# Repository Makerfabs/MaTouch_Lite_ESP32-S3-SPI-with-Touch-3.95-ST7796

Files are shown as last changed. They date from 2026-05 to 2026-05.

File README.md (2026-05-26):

# MaTouch_Lite_ESP32-S3-SPI-with-Touch-3.95-ST7796

## Introduction

The MaTouch Lite 3.95 adopts an SPI screen driven by ST7796 chip with a resolution of 480×320, matched with NS2009 resistive touch screen. It is equipped with ESP32-S3 main controller, built-in 16M Flash and 8M PSRAM. Adopting SPI display design, plenty of reserved GPIOs are available for secondary development via GPIO expansion interface. It also comes with SD card interface and USB native/USB2UART port.

Product Link: [MaTouch_Lite_ESP32-S3-SPI-with-Touch-3.95-ST7796](https://www.makerfabs.com/matouch-lite-esp32-s3-spi-resistive-touch-3-95-st7796.html)

Wiki Link:  [MaTouch_Lite_ESP32-S3-SPI-with-Touch-3.95-ST7796](https://wiki.makerfabs.com/MaTouch%20Lite%20ESP32_S3%20SPI%20with%20Touch%203.95%20ST7796.html)

Example：[LVGL_Touch](https://github.com/Makerfabs/MaTouch_Lite_ESP32-S3-SPI-with-Touch-3.95-ST7796#lvgl_touch)

## Feature

- Controller: ESP32-S3 controller 16M flash, 8M PSRAM
- Display: 3.95", 480x320 resolution , driver ST7796, SPI interface
- Touch Panel: Resistive, NS2009
- USB: 1 * USB_native, 1 * USB-to-UART
- USB-UART Driver: CH340K
- Power Supply: USB Type-C 5.0V(4.0V~5.25V); 3.7V Lipo battery
- Expansion interface: 2*JST1.25mm-4P GPIO, with cable included
- MicroSD Card Slot
- LCD Backlight control: Yes
- Arduino support: Yes
- LVGL support: Yes
- Operation temperature: -40℃ to +85℃

## Usage in Arduino IDE

- Install the Arduino IDE V1.8.19/V2.3.6
If you haven’t installed the ESP32 Board SDK yet, follow the steps in this [guide](https://wiki.makerfabs.com/Installing_ESP32_Add_on_in_Arduino_IDE.html) to get started quickly.

For the ESP32-S3 Development board version, we recommend using versions that have been verified, such as 2.0.16， which is more stable, and less prone to errors.

Note: Different computers may have different port numbers when connecting to a development board. Please select the correct port number based on the development board you are connecting to.

Please download the relevant driver libraries before using these demos.

1.Install Adafruit_BusIO v1.17.4

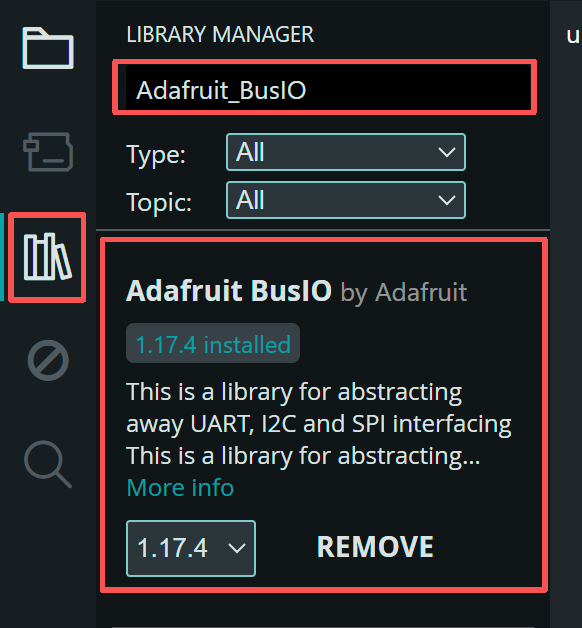
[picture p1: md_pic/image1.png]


2.Install Adafruit_SGP30_Sensor v2.0.3

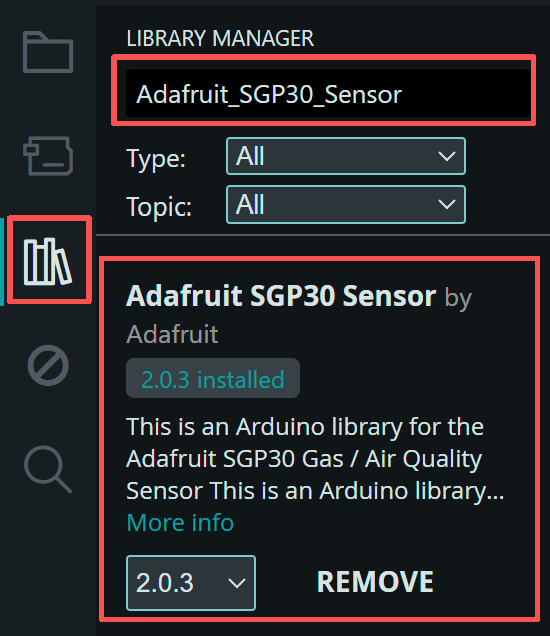
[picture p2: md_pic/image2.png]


3.Install Adafruit_SHT31_Library v2.2.2

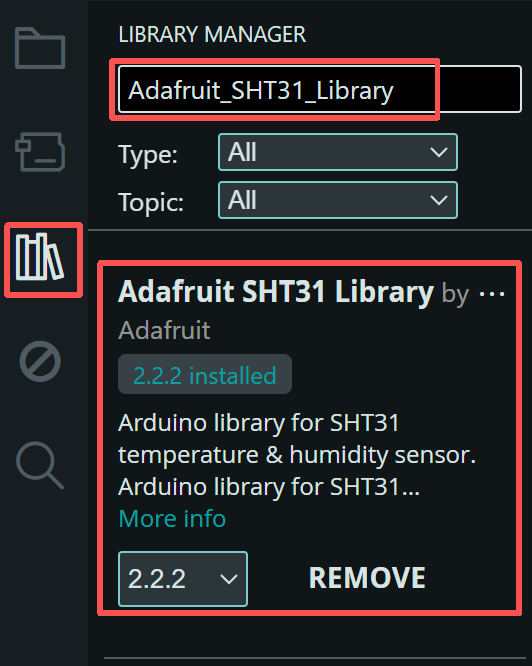
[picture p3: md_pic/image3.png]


## Example

### LVGL_Touch

This demonstration showcases the integrated application of display and touch. The screen initially shows an image with data such as temperature, humidity, CO2, TVOC,and touch point coordinates. If the screen is not touched within 10 seconds, it will automatically turn off. After the screen turns off, clicking on it will make it bright again and display the data.

- First, connect the Mabee module to the ESP32-S3 module correctly, as shown in the figure.

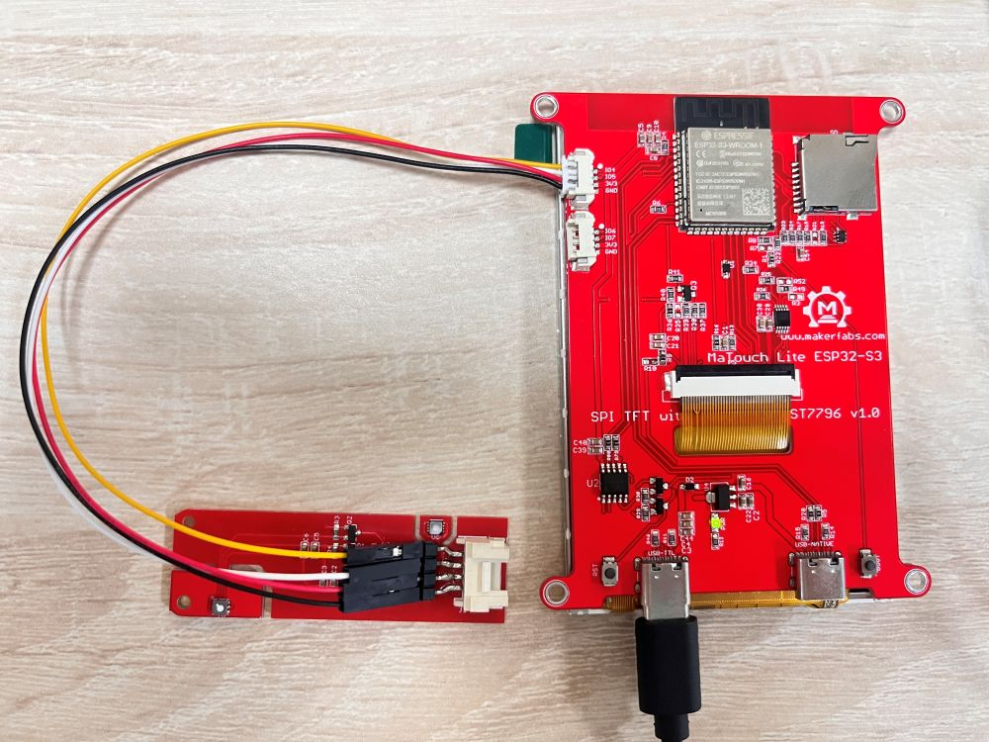
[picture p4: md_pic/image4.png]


- Download the library from [github](https://github.com/Makerfabs/MaTouch_Lite_ESP32-S3-SPI-with-Touch-3.95-ST7796/tree/main/example/LVGL_Touch/libraries)

Once the download is complete, copy these libraries into the Arduino library.

- The default is usually in the "C:\Users\Your username\Documents\Arduino\libraries"

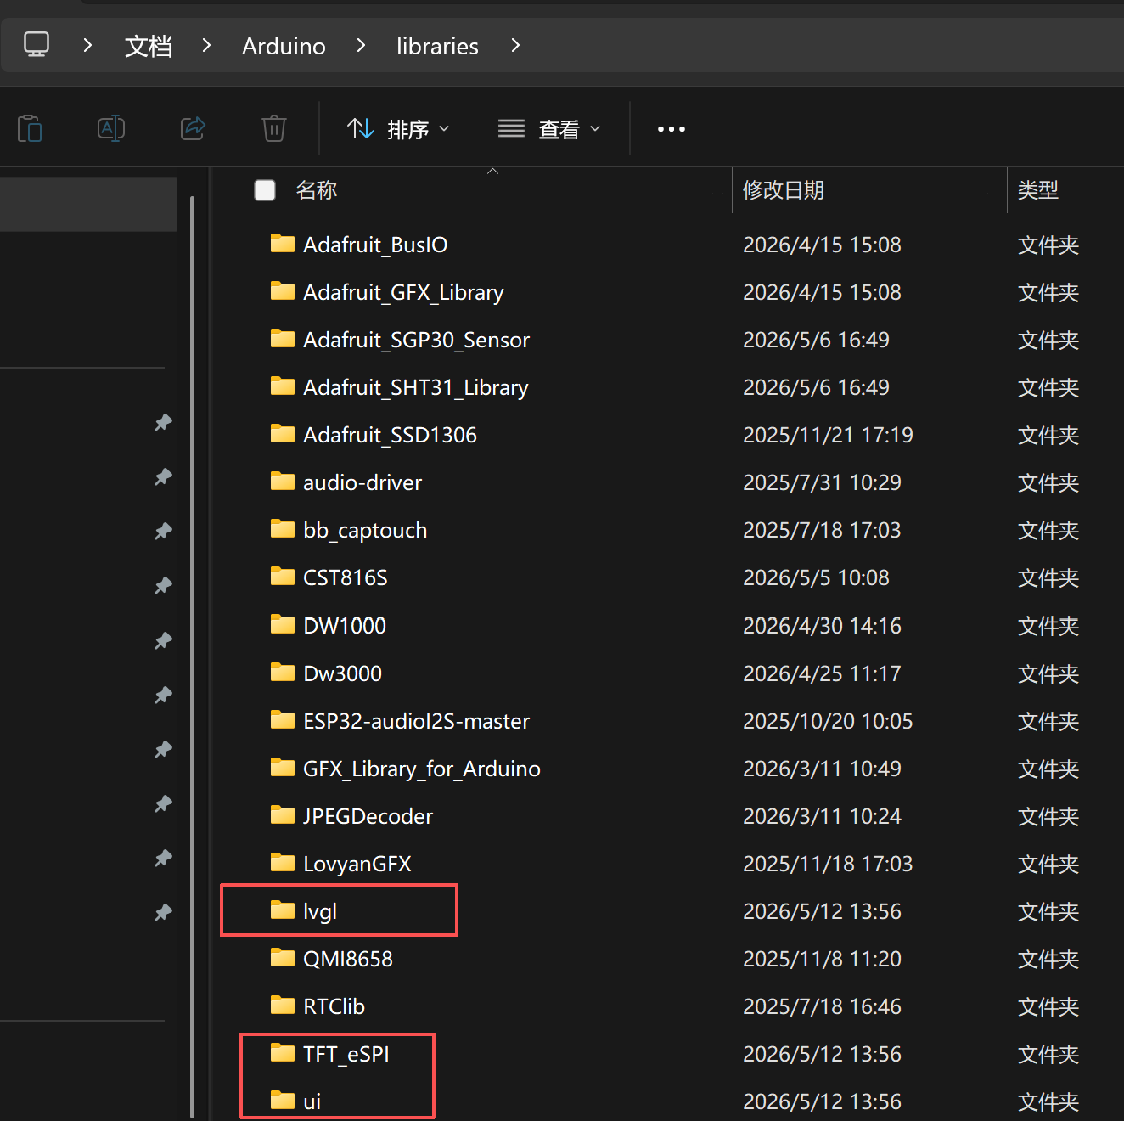
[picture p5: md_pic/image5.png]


**Note: If the UI, LVGL or TFT_eSPI library already exists in your Arduino libraries folder, please delete them first, then install the new version of the UI, LVGL or TFT_eSPI library.**

- Open the [LVGL_Touch](https://github.com/Makerfabs/MaTouch_Lite_ESP32-S3-SPI-with-Touch-3.95-ST7796/blob/main/example/LVGL_Touch/ui/ui.ino) by Arduino.

Connect the board to the computer using a Type-C USB data cable and via USB-TTL, and select the development board "ESP32S3 Dev Module" and the port.

- Select "Tools > board:"xxx" > ESP32 > ESP32S3 Dev Module".
- Select "Tools > Port",Select the port number of the board.
- Select Flash Size is 16MB(128MB), Partition Scheme is 16M Flash (3MB APP/9.9MB FATFS), PSRAM is OPI PSRAM.

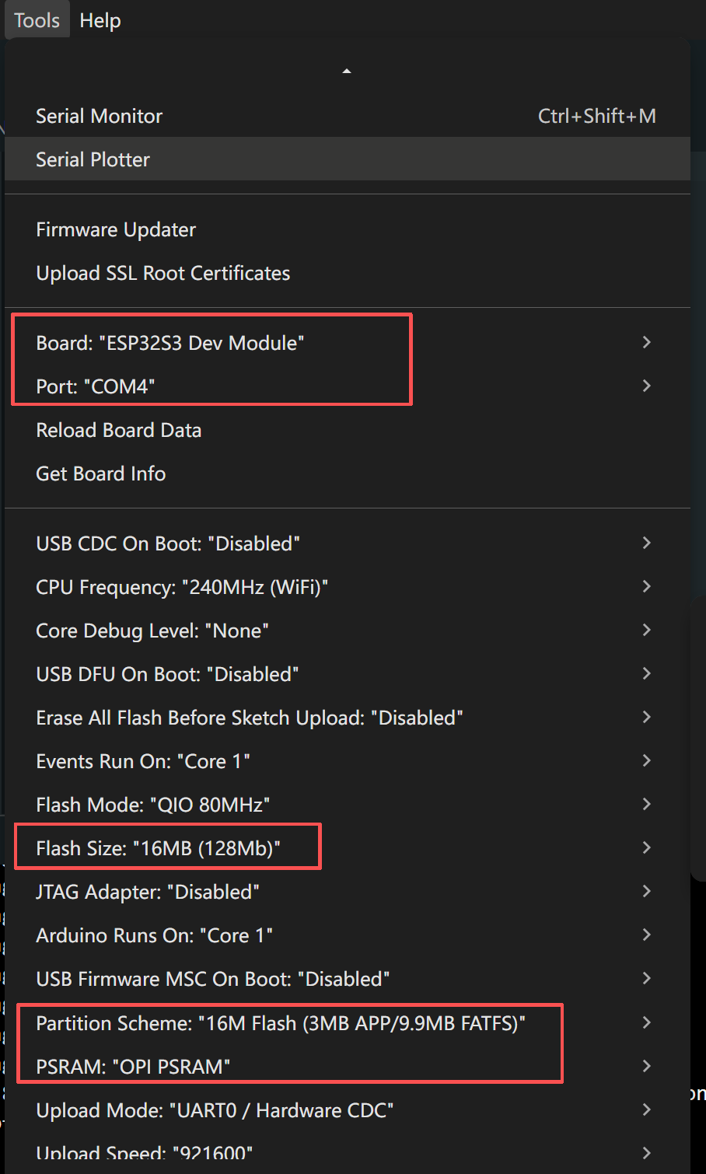
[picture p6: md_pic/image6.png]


- Click the Upload button in the Arduino IDE and wait a few times while the code compiles and uploads to your board.

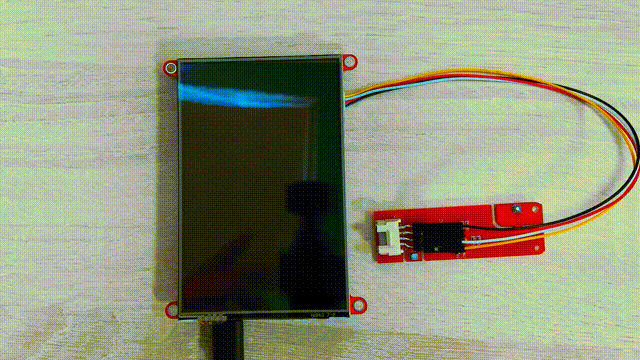
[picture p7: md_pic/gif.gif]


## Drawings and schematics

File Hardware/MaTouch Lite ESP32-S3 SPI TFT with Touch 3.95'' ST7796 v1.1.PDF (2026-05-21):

POWER | USB to TTL

# SD Card

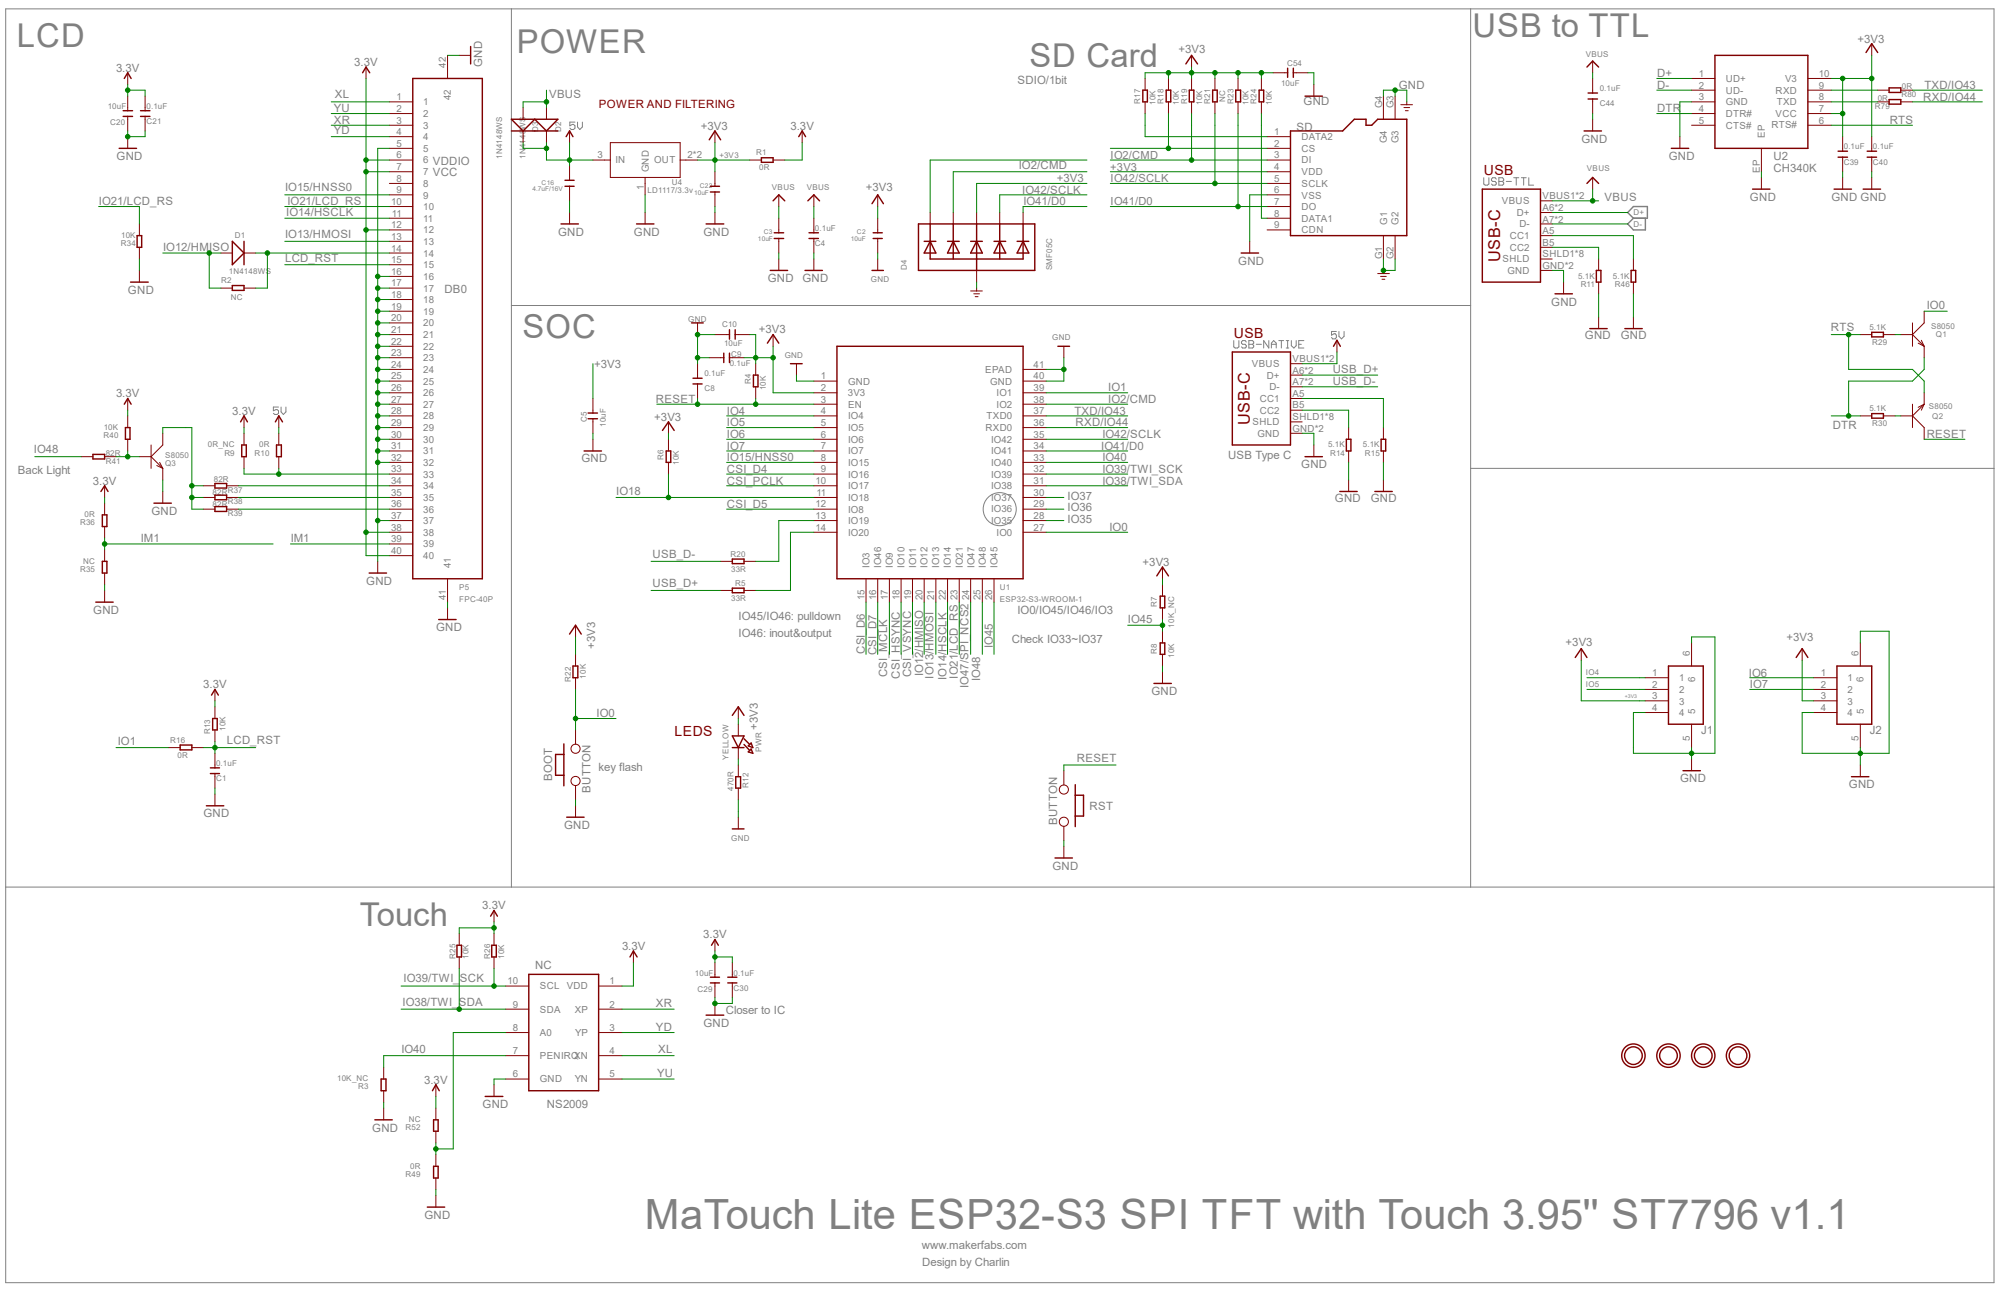
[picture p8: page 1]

MaTouch Lite ESP32-S3 SPI TFT with Touch 3.95'' ST7796 v1.1

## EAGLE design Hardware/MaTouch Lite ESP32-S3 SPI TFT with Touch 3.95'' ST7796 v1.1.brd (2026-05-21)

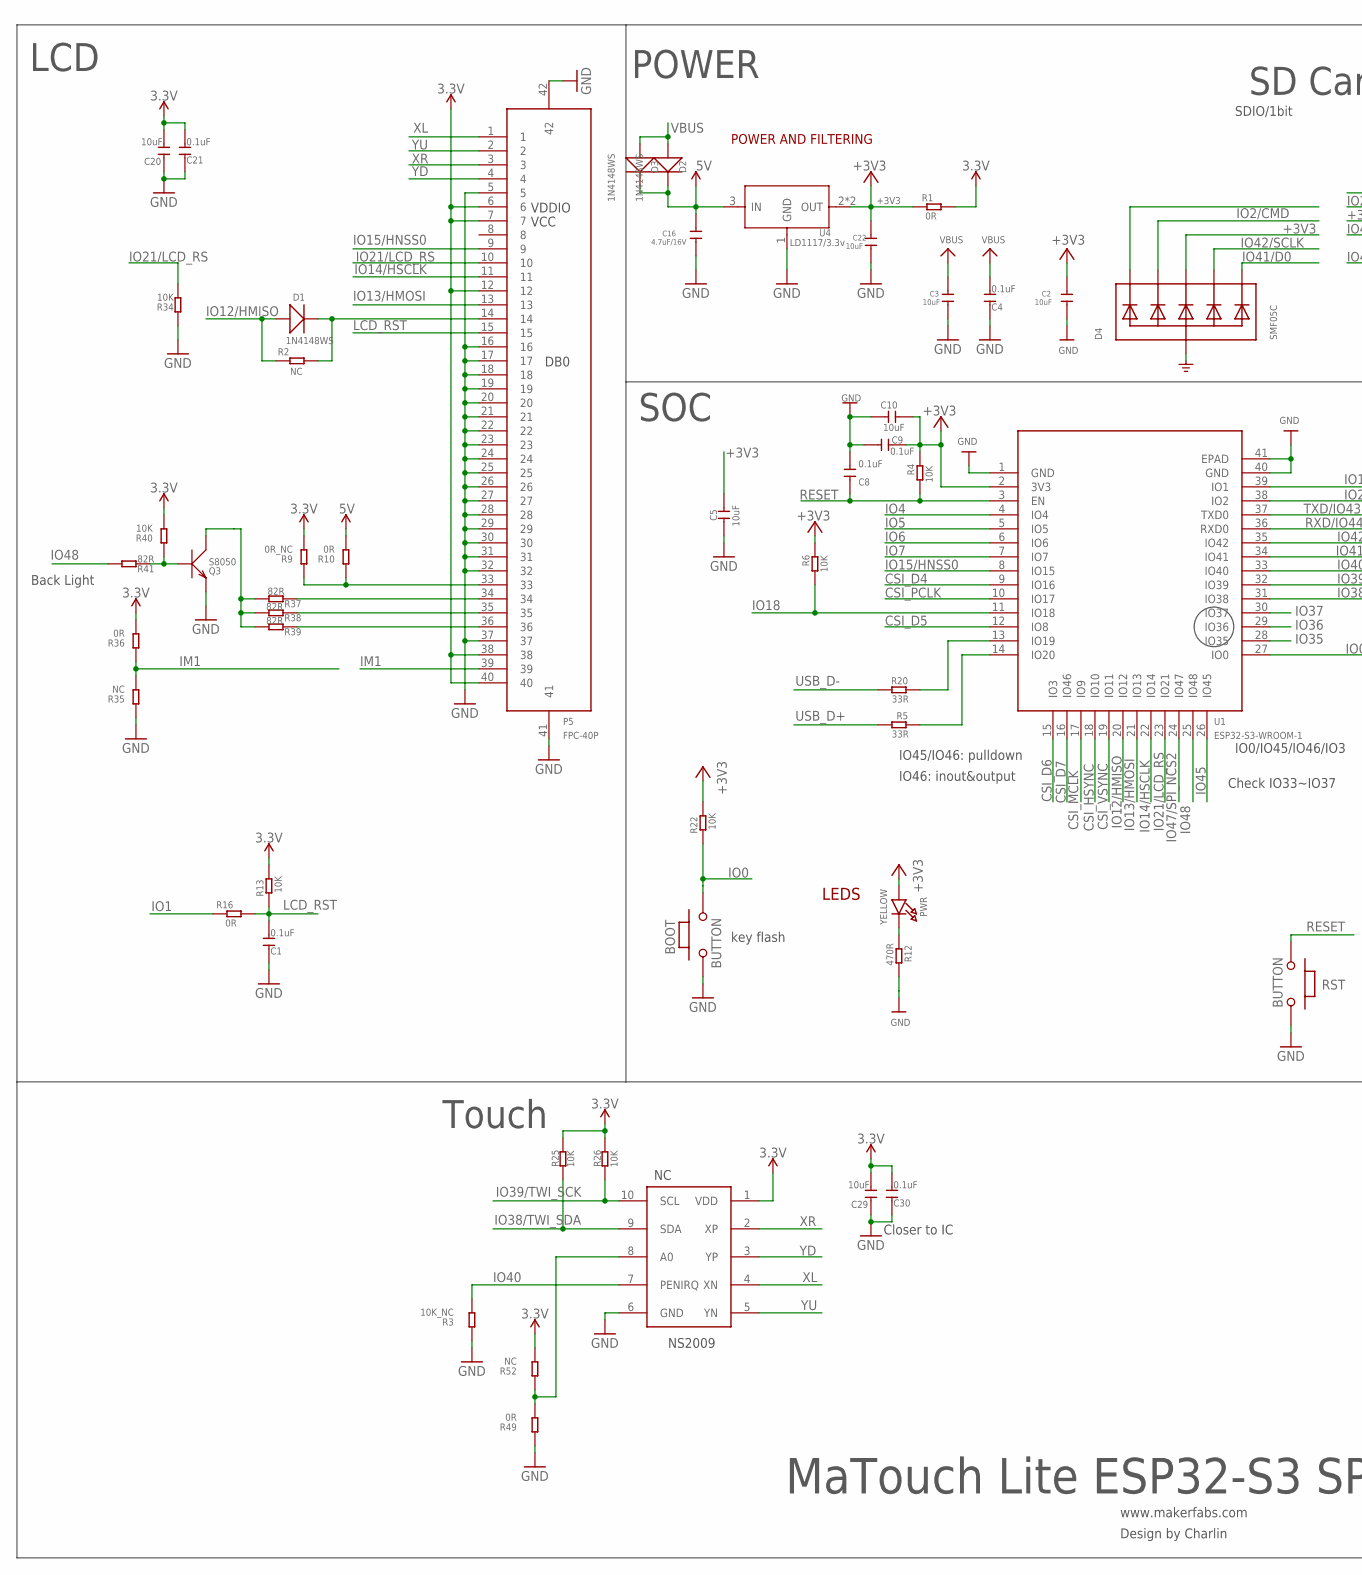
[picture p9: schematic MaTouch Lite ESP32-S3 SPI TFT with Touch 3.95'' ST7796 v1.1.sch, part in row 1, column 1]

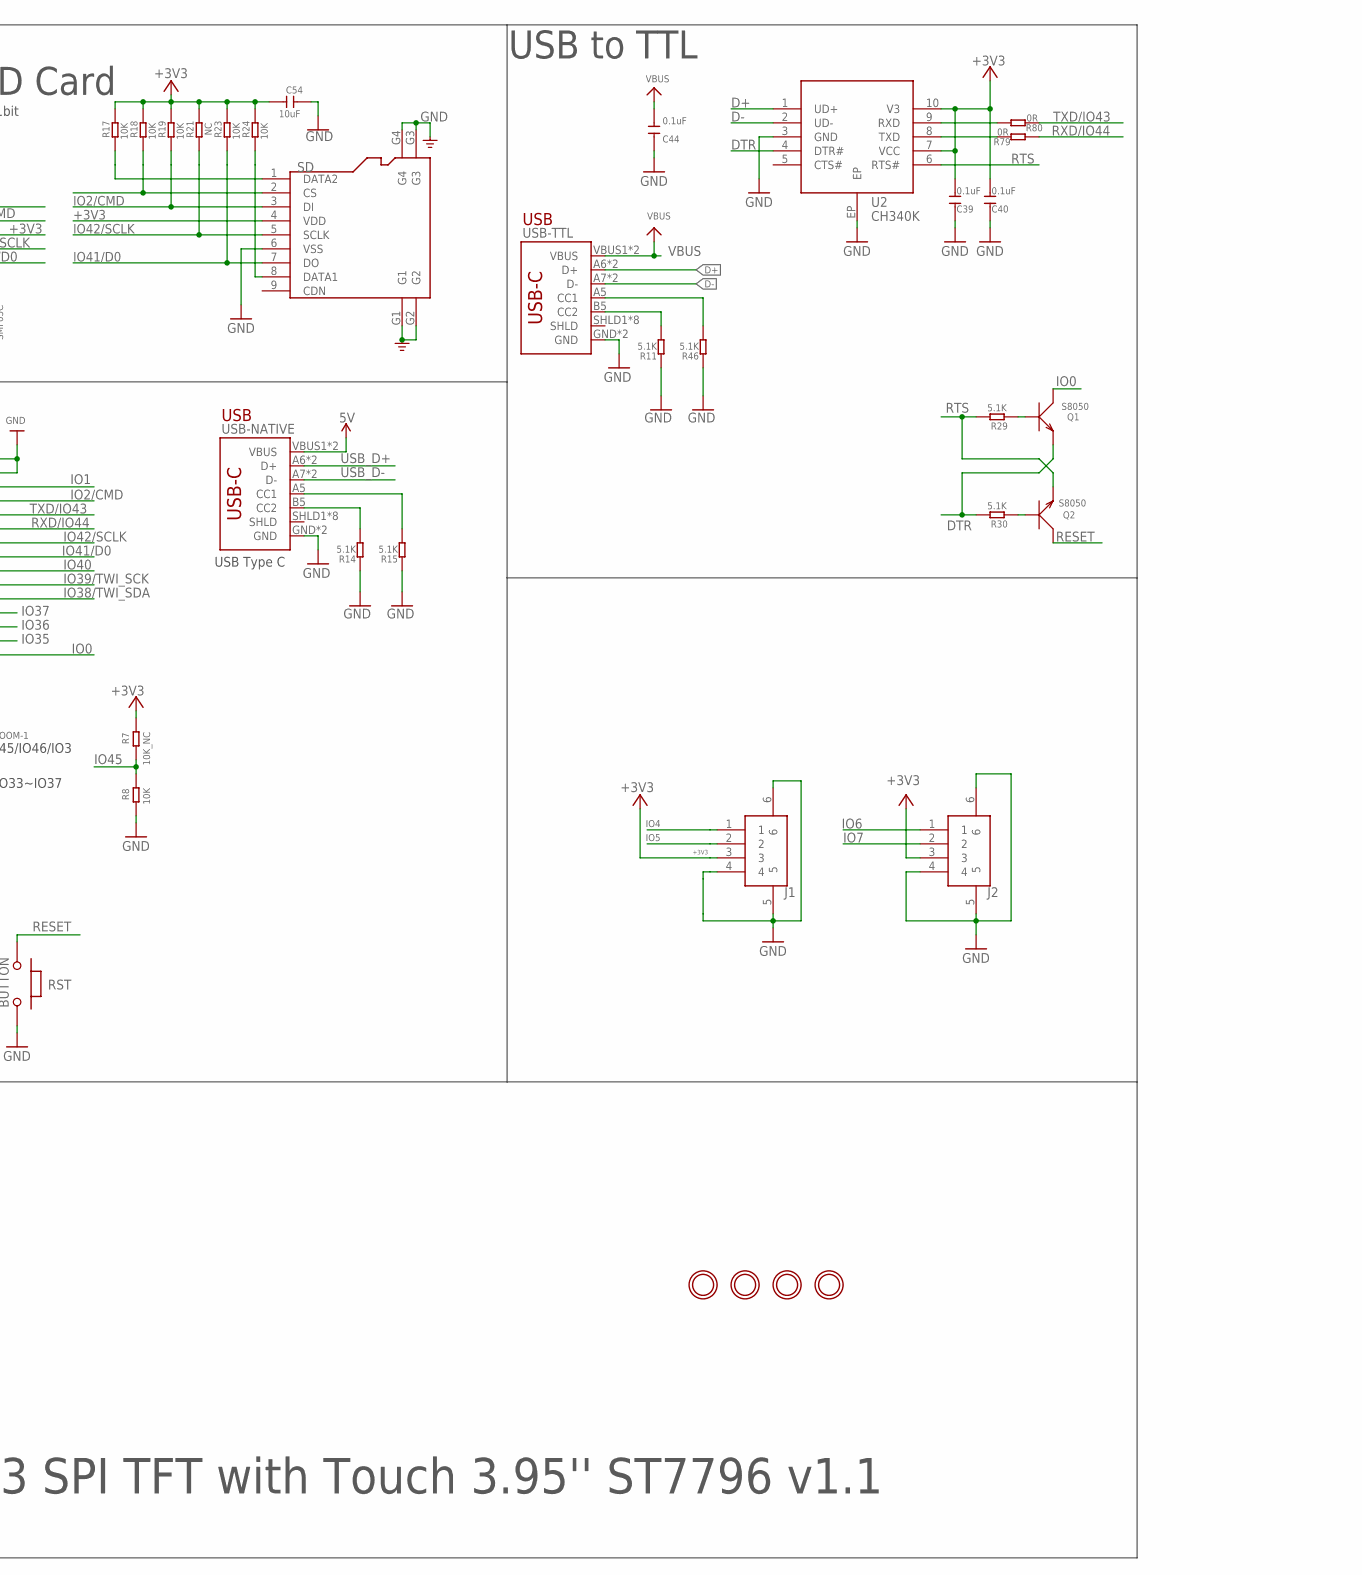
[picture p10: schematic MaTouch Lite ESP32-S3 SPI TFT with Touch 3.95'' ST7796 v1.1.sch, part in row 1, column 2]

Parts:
BOOT: BUTTON; 157SW
C1, C4, C8, C9, C21, C30, C39, C40, C44: 0.1uF; DISCRETE_C0603
C2, C3, C22: 10uF; 0603
C5, C10, C20, C29, C54: 10uF; DISCRETE_C0603
C16: 4.7uF/16V; 0603
D1, D2, D3: 1N4148WS; SOD323
D4: SMF05C; SOT363
H1, H2, H3, H4: MICROBUILDER_MOUNTINGHOLE3.0THIN; MICROBUILDER_MOUNTINGHOLE_3.0_PLATEDTHIN
J1, J2: CON4-1.25P-SMD; SMD4-125P-1000L525W350H
P5: FPC-40P; SMD42-50P-2560L490W
PWR: YELLOW; CHIPLED_0805_NOOUTLINE
Q1, Q2, Q3: S8050; SOT23
R1, R16, R79, R80: 0R; R0603
R2, R21: NC; R0603
R3: 10K_NC; DISCRETE_R0603
R4, R6, R8, R13, R17, R18, R19, R22, R23, R24, R25, R26: 10K; R0603
R5, R20: 33R; R0603
R7: 10K_NC; R0603
R9: 0R_NC; DISCRETE_R0603
R10, R36, R49: 0R; DISCRETE_R0603
R11, R14, R15, R46: 5.1K; DISCRETE_R0603
R12: 470R; R0603
R29, R30: 5.1K; R0603
R34, R40: 10K; DISCRETE_R0603
R35, R52: NC; DISCRETE_R0603
R37, R38, R39, R41: 82R; DISCRETE_R0603
RST: BUTTON; 157SW
SD: HOLDER-MICROSD-9P; 9P-SMD-W/-RING
U1: ESP32-S3-WROOM-1
U2: CH340K; ESOP-10-EP-150MIL
U4: LD1117/3.3v; SOT89
U8: NS2009; MSOP10
USB-NATIVE: USB_C5; USB-C-16P-5
USB-TTL: USB_C5; USB-C-16P-5

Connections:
5V: C16.1, D2.-, D3.-, R10.2, U4.3 (IN), USB-NATIVE.VBUS1 (VBUS), USB-NATIVE.VBUS2 (VBUS)
+3V3: C2.1, C5.1, C9.1, C10.1, C20.2, C21.2, C22.1, C29.2, C30.2, C39.2, C40.2, C54.2, D4.4 (C3), J1.3, J2.3, P5.6, P5.7, P5.12, P5.38, P5.40, PWR.A, R1.1, R1.2, R4.2, R6.2, R7.2, R9.2, R13.2, R17.2, R18.2, R19.2, R21.2, R22.2, R23.2, R24.2, R25.2, R26.2, R36.2, R40.2, R52.2, SD.4 (VDD), U1.2 (3V3), U2.7 (VCC), U2.10 (V3), U4.2 (OUT), U4.4 (OUT), U8.1 (VDD)
CSI_D4: U1.9 (IO16)
CSI_D5: U1.12 (IO8)
CSI_D6: U1.15 (IO3)
CSI_D7: U1.16 (IO46)
CSI_HSYNC: U1.18 (IO10)
CSI_MCLK: U1.17 (IO9)
CSI_PCLK: U1.10 (IO17)
CSI_VSYNC: U1.19 (IO11)
D+: U2.1 (UD+), USB-TTL.A6 (D+), USB-TTL.B6 (D+)
D-: U2.2 (UD-), USB-TTL.A7 (D-), USB-TTL.B7 (D-)
DTR: Q1.2 (E), R30.2, U2.4 (DTR#)
GND: BOOT.1, C1.1, C2.2, C3.2, C4.1, C5.2, C8.2, C9.2, C10.2, C16.2, C20.1, C21.1, C22.2, C29.1, C30.1, C39.1, C40.1, C44.1, C54.1, D4.2 (A), J1.4, J1.5, J1.6, J2.4, J2.5, J2.6, P5.5, P5.16, P5.17, P5.18, P5.19, P5.20, P5.21, P5.22, P5.23, P5.24, P5.25, P5.26, P5.27, P5.28, P5.29, P5.30, P5.31, P5.32, P5.37, P5.41, P5.42, Q3.2 (E), R3.1, R8.1, R11.1, R12.2, R14.1, R15.1, R34.1, R35.1, R46.1, R49.1, RST.1, SD.6 (VSS), SD.G1, SD.G2, SD.G3, SD.G4, U1.1 (GND), U1.40 (GND), U1.41 (EPAD), U2.3 (GND), U2.EP, U4.1 (GND), U8.6 (GND), USB-NATIVE.GND, USB-NATIVE.GND2 (GND), USB-TTL.GND, USB-TTL.GND2 (GND)
IM1: P5.39, R35.2, R36.1
IO0: BOOT.2, Q1.3 (C), R22.1, U1.27 (IO0)
IO1: R16.1, U1.39 (IO1)
IO1/CS: D4.1 (C1), R18.1, SD.2 (CS)
IO2/CMD: D4.3 (C2), R19.1, SD.3 (DI), U1.38 (IO2)
IO4: J1.1, U1.4 (IO4)
IO5: J1.2, U1.5 (IO5)
IO6: J2.1, U1.6 (IO6)
IO7: J2.2, U1.7 (IO7)
IO12/HMISO: D1.+, R2.1, U1.20 (IO12)
IO13/HMOSI: P5.13, U1.21 (IO13)
IO14/HSCLK: P5.11, U1.22 (IO14)
IO15/HNSS0: P5.9, U1.8 (IO15)
IO18: R6.1, U1.11 (IO18)
IO21/LCD_RS: P5.10, R34.2, U1.23 (IO21)
IO35: U1.28 (IO35)
IO36: U1.29 (IO36)
IO37: U1.30 (IO37)
IO38/TWI_SDA: R25.1, U1.31 (IO38), U8.9 (SDA)
IO39/TWI_SCK: R26.1, U1.32 (IO39), U8.10 (SCL)
IO40: R3.2, U1.33 (IO40), U8.7 (PENIRQ)
IO41/D0: D4.6 (C5), R23.1, SD.7 (DO), U1.34 (IO41)
IO42/SCLK: D4.5 (C4), R21.1, SD.5 (SCLK), U1.35 (IO42)
IO45: R7.1, R8.2, U1.26 (IO45)
IO47/SPI_NCS2: U1.24 (IO47)
IO48: R41.2, U1.25 (IO48)
LCD_RST: C1.2, P5.15, R13.1, R16.2
unnamed: R46.2, USB-TTL.A5 (CC1)
unnamed: D1.-, P5.14, R2.2
unnamed: Q2.1 (B), R30.1
unnamed: PWR.C, R12.1
unnamed: Q1.1 (B), R29.1
unnamed: R15.2, USB-NATIVE.A5 (CC1)
unnamed: R20.2, U1.13 (IO19)
unnamed: R5.2, U1.14 (IO20)
unnamed: R14.2, USB-NATIVE.B5 (CC2)
unnamed: R11.2, USB-TTL.B5 (CC2)
unnamed: P5.34, R37.1
unnamed: P5.35, R38.1
unnamed: P5.36, R39.1
unnamed: Q3.1 (B), R40.1, R41.1
unnamed: Q3.3 (C), R37.2, R38.2, R39.2
unnamed: R49.2, R52.1, U8.8 (A0)
unnamed: P5.33, R9.1, R10.1
unnamed: R80.2, U2.9 (RXD)
unnamed: R79.2, U2.8 (TXD)
unnamed: R17.1, SD.1 (DATA2)
unnamed: R24.1, SD.8 (DATA1)
RESET: C8.1, Q2.3 (C), R4.1, RST.2, U1.3 (EN)
RTS: Q2.2 (E), R29.2, U2.6 (RTS#)
RXD/IO44: R79.1, U1.36 (RXD0)
TXD/IO43: R80.1, U1.37 (TXD0)
USB_D+: R5.1, USB-NATIVE.A6 (D+), USB-NATIVE.B6 (D+)
USB_D-: R20.1, USB-NATIVE.A7 (D-), USB-NATIVE.B7 (D-)
VBUS: C3.1, C4.2, C44.2, D2.+, D3.+, USB-TTL.VBUS1 (VBUS), USB-TTL.VBUS2 (VBUS)
XL: P5.1, U8.4 (XN)
XR: P5.3, U8.2 (XP)
YD: P5.4, U8.3 (YP)
YU: P5.2, U8.5 (YN)

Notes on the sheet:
www.makerfabs.com
Design by Charlin
LEDS
POWER AND FILTERING
key flash
MaTouch Lite ESP32-S3 SPI TFT with Touch 3.95'' ST7796 v1.1
POWER
USB to TTL
SD Card
NS2009
Closer to IC
Back Light
IO45/IO46: pulldown
IO46: inout&output
USB
USB Type C
IO0/IO45/IO46/IO3
Check IO33~IO37
LCD
SOC
Touch
VDDIO
VCC
DB0
SDIO/1bit

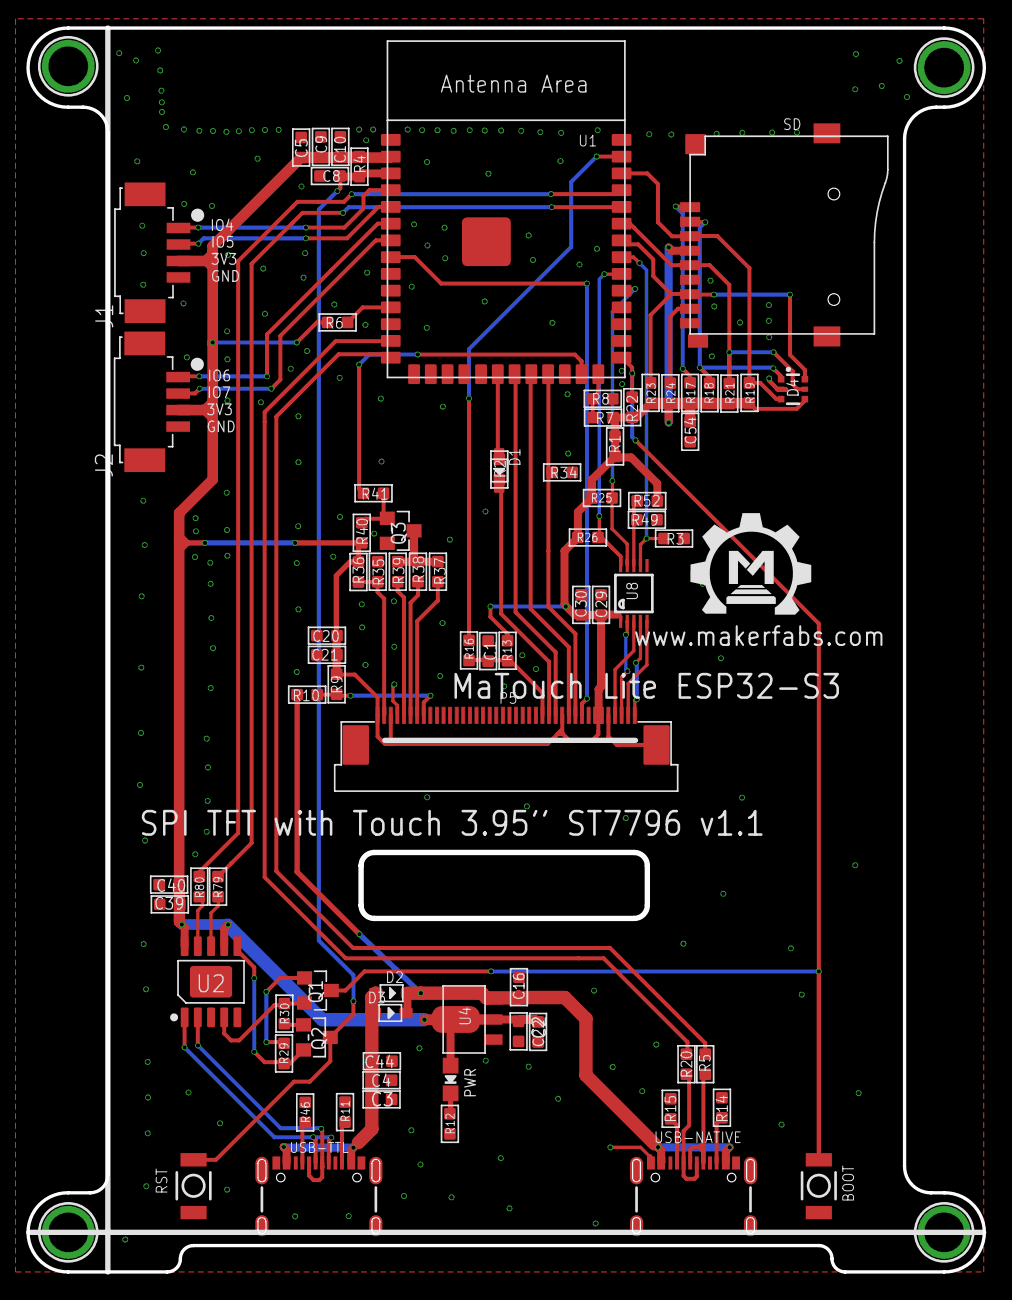
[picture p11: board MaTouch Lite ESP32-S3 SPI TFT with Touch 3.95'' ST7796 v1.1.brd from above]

Board: 2 copper layers, 72.5 x 94.3 mm, 84 parts (0 on the bottom side), 61 nets.

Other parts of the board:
U$1: MAKERFABS_0.3

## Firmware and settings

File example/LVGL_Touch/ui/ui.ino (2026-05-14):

#include <lvgl.h>
#include <TFT_eSPI.h>
#include <ui.h>

#include <SPI.h>
#include <Wire.h>
#include "NS2009.h"
#include "Adafruit_SGP30.h"
#include "Adafruit_SHT31.h"


#define I2C_SDA_PIN 5
#define I2C_SCL_PIN 4
#define TOUCH_SDA_PIN 38
#define TOUCH_SCL_PIN 39


Adafruit_SHT31 sht31;
Adafruit_SGP30 sgp;
NS2009 touch(0x48, false, false);

/*Don't forget to set Sketchbook location in File/Preferences to the path of your UI project (the parent foder of this INO file)*/
unsigned long lastSensorRead = 0;
unsigned long lastTouchTime = 0;
bool screenOn = true;
const unsigned long SCREEN_OFF_MS = 10000;

float h = 0.0;
float t = 0.0;
int TVOC = 0;
int eCO2 = 0;

int touchX = 0;
int touchY = 0;
bool isTouched = false;

/*Change to your screen resolution*/
static const uint16_t screenWidth  = 320;
static const uint16_t screenHeight = 480;

static lv_disp_draw_buf_t draw_buf;
static lv_color_t buf[ screenWidth * screenHeight / 10 ];

TFT_eSPI tft = TFT_eSPI(screenWidth, screenHeight); /* TFT instance */

#if LV_USE_LOG != 0
/* Serial debugging */
void my_print(const char * buf)
{
    Serial.printf(buf);
    Serial.flush();
}
#endif

/* Display flushing */
void my_disp_flush( lv_disp_drv_t *disp, const lv_area_t *area, lv_color_t *color_p )
{
    uint32_t w = ( area->x2 - area->x1 + 1 );
    uint32_t h = ( area->y2 - area->y1 + 1 );

    tft.startWrite();
    tft.setAddrWindow( area->x1, area->y1, w, h );
    tft.pushColors( ( uint16_t * )&color_p->full, w * h, true );
    tft.endWrite();

    lv_disp_flush_ready( disp );
}

/*Read the touchpad*/
void my_touchpad_read( lv_indev_drv_t * indev_driver, lv_indev_data_t * data )
{
    touch.Scan();

    if (touch.Touched) {
        data->state = LV_INDEV_STATE_PR;
        data->point.x = touch.X;
        data->point.y = touch.Y;
        touchX = touch.X;
        touchY = touch.Y;
        isTouched = true;
        lastTouchTime = millis();
    } else {
        data->state = LV_INDEV_STATE_REL;
    }
}

uint32_t getAbsoluteHumidity(float temperature, float humidity)
{
    const float absoluteHumidity = 216.7f * ((humidity / 100.0f) * 6.112f * exp((17.62f * temperature) / (243.12f + temperature)) / (273.15f + temperature));
    const uint32_t absoluteHumidityScaled = static_cast<uint32_t>(1000.0f * absoluteHumidity);
    return absoluteHumidityScaled;
}

void sensor_init()
{
    Wire.begin(I2C_SDA_PIN, I2C_SCL_PIN);
    Wire.setClock(100000UL);
    delay(100);

    if (!sht31.begin(0x44)) {
        Serial.println("SHT31 not found");
    }
    if (!sgp.begin()) {
        Serial.println("SGP30 not found");
    }
}


void updateSensorData()
{
    float humidity = sht31.readHumidity();
    float temperature = sht31.readTemperature();

    if (!isnan(temperature)) t = temperature;
    if (!isnan(humidity)) h = humidity;

    sgp.setHumidity(getAbsoluteHumidity(t, h));

    if (sgp.IAQmeasure()) {
        TVOC = sgp.TVOC;
        eCO2 = sgp.eCO2;
    }

    static char lastT[32] = "";
    static char lastH[32] = "";
    static char lastC[32] = "";
    static char lastOC[32] = "";
    char text[32];

    sprintf(text, "%.1f °C", t);
    if (strcmp(text, lastT) != 0) {
        strcpy(lastT, text);
        lv_label_set_text(ui_Label2, text);
    }

    sprintf(text, "%.1f %%", h);
    if (strcmp(text, lastH) != 0) {
        strcpy(lastH, text);
        lv_label_set_text(ui_Label4, text);
    }

    sprintf(text, "%d ppm", eCO2);
    if (strcmp(text, lastC) != 0) {
        strcpy(lastC, text);
        lv_label_set_text(ui_Label6, text);
    }

    sprintf(text, "%d ppb", TVOC);
    if (strcmp(text, lastOC) != 0) {
        strcpy(lastOC, text);
        lv_label_set_text(ui_Label8, text);
    }

}

void updateTouchdata()
{
    static char lastTouchTxt[32] = "";
    char touchText[32];
    
    if (isTouched) {
        sprintf(touchText, "X:%3d  Y:%3d", touchX, touchY);
    } else {
        sprintf(touchText, "X:---  Y:---");
    }

    if (strcmp(touchText, lastTouchTxt) != 0) {
        strcpy(lastTouchTxt, touchText);
        lv_label_set_text(ui_Label9, touchText);
    }
}

void checkScreenAutoOff() {
    if (screenOn && millis() - lastTouchTime > SCREEN_OFF_MS) {
        screenOn = false;
        digitalWrite(TFT_BL, LOW);
    }
    else if (!screenOn && touch.Touched) {
        screenOn = true;
        digitalWrite(TFT_BL, HIGH);
        lastTouchTime = millis();
    }
}

void setup()
{
    Serial.begin( 115200 ); /* prepare for possible serial debug */

    pinMode(TFT_BL, OUTPUT);
    digitalWrite(TFT_BL, HIGH);

    String LVGL_Arduino = "Hello Arduino! ";
    LVGL_Arduino += String('V') + lv_version_major() + "." + lv_version_minor() + "." + lv_version_patch();

    Serial.println( LVGL_Arduino );
    Serial.println( "I am LVGL_Arduino" );

    lv_init();

#if LV_USE_LOG != 0
    lv_log_register_print_cb( my_print ); /* register print function for debugging */

#endif

    tft.begin();          /* TFT init */
    tft.setRotation( 0 ); /* Landscape orientation, flipped */

    lv_disp_draw_buf_init( &draw_buf, buf, NULL, screenWidth * screenHeight / 10 );



    /*Initialize the display*/
    static lv_disp_drv_t disp_drv;
    lv_disp_drv_init( &disp_drv );
    /*Change the following line to your display resolution*/
    disp_drv.hor_res = screenWidth;
    disp_drv.ver_res = screenHeight;
    disp_drv.flush_cb = my_disp_flush;
    disp_drv.draw_buf = &draw_buf;
    lv_disp_drv_register( &disp_drv );

    /*Initialize the (dummy) input device driver*/
    static lv_indev_drv_t indev_drv;
    lv_indev_drv_init( &indev_drv );
    indev_drv.type = LV_INDEV_TYPE_POINTER;
    indev_drv.read_cb = my_touchpad_read;
    lv_indev_drv_register( &indev_drv );

    sensor_init();

    Wire1.begin(TOUCH_SDA_PIN, TOUCH_SCL_PIN);
    Wire1.setClock(100000);
    touch.Calibrate(CALIBRATE_MIN_X, CALIBRATE_MAX_X, CALIBRATE_MIN_Y, CALIBRATE_MAX_Y);

    ui_init();

    updateSensorData();

    Serial.println( "Setup done" );
}

void loop()
{
    lv_timer_handler(); /* let the GUI do its work */
    if (millis() - lastSensorRead > 2000) {
        lastSensorRead = millis();
        updateSensorData();
    }
    updateTouchdata();
    checkScreenAutoOff();
    delay(5);
}

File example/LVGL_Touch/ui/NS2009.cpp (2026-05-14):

#include <Wire.h>
#include <Arduino.h>
#include "NS2009.h"

int Map_Data (int Data, int InMin, int InMax, int OutMin, int OutMax)
{
  if (Data < InMin)
    Data = InMin;
  if (Data > InMax)
    Data = InMax;
  return ((Data-InMin)*(OutMax-OutMin))/(InMax-InMin)+OutMin;
}

NS2009::NS2009 (void)
{
  Address = DEFAULT_NS2009_ADDR;
  FlipX = false;
  FlipY = false;
}

NS2009::NS2009 (unsigned char _Address)
{
  Address = _Address;
  FlipX = false;
  FlipY = false;
}

NS2009::NS2009 (bool _FlipX, bool _FlipY)
{
  Address = DEFAULT_NS2009_ADDR;
  FlipX = _FlipX;
  FlipY = _FlipY;
}

NS2009::NS2009 (unsigned char _Address, bool _FlipX, bool _FlipY)
{
  Address = _Address;
  FlipX = _FlipX;
  FlipY = _FlipY;
}

unsigned int NS2009::ReadRegister (unsigned char Command)
{
  unsigned char ReadData[2], i=0;
  Wire1.beginTransmission(Address);
  Wire1.write(&Command, 1);
  Wire1.endTransmission();
  Wire1.requestFrom(Address, 2);
  while (Wire1.available())
    ReadData[i++] = Wire1.read();
  return (ReadData[0] << 4) | (ReadData[1] >> 4);
}

void NS2009::Calibrate ()
{
  int P1X, P1Y, P2X, P2Y;
  Serial.println ("Touch corner of the screen\n\r");
  ScanBlocking ();
  P1X = RawX;
  P1Y = RawY;
  Serial.println ("Touch registered! Touch an opposite corner!\n\r");
  while (CheckTouched ());

  // opposite corner
  ScanBlocking ();
  P2X = RawX;
  P2Y = RawY;
  Serial.println ("Second touch registered!\n\r");
  while (CheckTouched ());

  MinX = MIN(P1X, P2X);
  MaxX = MAX(P1X, P2X);
  MinY = MIN(P1Y, P2Y);
  MaxY = MAX(P1Y, P2Y);
}

void NS2009::Calibrate (int _MinX, int _MaxX, int _MinY, int _MaxY)
{
  MinX = _MinX;
  MaxX = _MaxX;
  MinY = _MinY;
  MaxY = _MaxY;
}

bool NS2009::CheckTouched ()
{
  do
  {
    RawZ = ReadRegister(NS2009_READ_Z);
  }
  while (RawZ == 0xFFF);  // sometimes the I2C reading gives a false positive by returning only ones ==> 0xFFF = 4095
  Touched = (RawZ > THRESHOLD_Z);
  return Touched;
}

void NS2009::Scan ()
{
  CheckTouched ();
  RawX = ReadRegister(NS2009_READ_X);
  X = Map_Data (RawX, MinX, MaxX, 0, SCREEN_SIZE_X);
  RawY = ReadRegister(NS2009_READ_Y);
  Y = Map_Data (RawY, MinY, MaxY, 0, SCREEN_SIZE_Y);
  if (FlipX)
    X = SCREEN_SIZE_X - X;
  if (FlipY)
    Y = SCREEN_SIZE_Y - Y;
}

void NS2009::ScanBlocking ()
{
  do
  {
    CheckTouched ();
  }
  while (!Touched);
  RawX = ReadRegister(NS2009_READ_X);
  X = Map_Data (RawX, MinX, MaxX, 0, SCREEN_SIZE_X);
  RawY = ReadRegister(NS2009_READ_Y);
  Y = Map_Data (RawY, MinY, MaxY, 0, SCREEN_SIZE_Y);
  if (FlipX)
    X = SCREEN_SIZE_X - X;
  if (FlipY)
    Y = SCREEN_SIZE_Y - Y;
}

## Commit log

2026-05-14 Add code
    [MaTouch Lite ESP32-S3 SPI TFT with Touch 3.95'' ST7796 v1.0.sch]
2026-05-14 Add Schematic Diagram
2026-05-20 Add hardware
    [MaTouch Lite ESP32-S3 SPI TFT with Touch 3.95'' ST7796 v1.1.brd, MaTouch Lite ESP32-S3 SPI TFT with Touch 3.95'' ST7796 v1.1.sch]

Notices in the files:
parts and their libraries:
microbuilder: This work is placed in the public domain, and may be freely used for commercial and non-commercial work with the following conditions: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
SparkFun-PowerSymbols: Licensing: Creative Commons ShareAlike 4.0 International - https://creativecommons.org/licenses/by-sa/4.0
